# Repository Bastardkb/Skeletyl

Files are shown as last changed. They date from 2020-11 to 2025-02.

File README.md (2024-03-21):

# Skeletyl

Compact and silent Dactyl-like keyboard for ergo lovers.

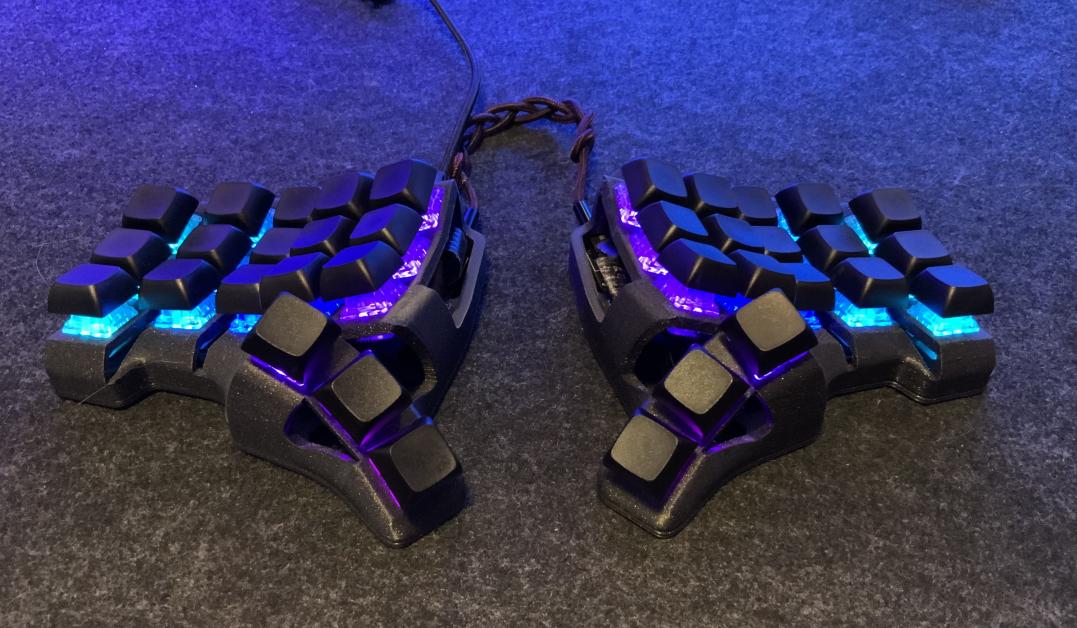
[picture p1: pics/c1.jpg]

*picture: trekdemow*

# Required components

## 3d prints

### Important note on V4/V3

The revision 4 of the skeletyl introduces drastic changes with the bottom plate. It reuses the positioning of the screws of the Charybdis Nano, so that the Organic tent can be re-used. It also uses new voronoi-style plates.

When choosing a model to print, be mindful of the version you choose. The files in the `V3` folder are **not** compatible with the V4 case and alien tents. Unless you want to use one of the `V3` mods, we recommend using the latest version `V4`.

### Print files and instructions

The STL files are included in this Github repository, in the `V4` folder.

Please find detailed instructions on how to print the case on the online instructions linked below.

| Description | File | Notes |
| --- | --- | --- |
| Right case | `V4/case_v4_vXY.stl` | XY version will vary |
| Left case | | Mirror the right case in your slicer |
| Right plate** | `V4/plates/plate_v4_vXY.stl` | XY version will vary |
| Left plate | | Mirror the right case in your slicer |
| Tent - right | [Charybdis nano tent](https://github.com/Bastardkb/Charybdis/tree/main/files/3x5%20nano/tent/alien) | Optional `Alien` tent, use the one from the Charybdis Nano* |
| Tent - left | | Mirror the right tent in your slicer* |

*If you are printing tents, there are multiple ones available for the Charybdis Nano, and only the `Alien` version is compatible with the Skeletyl V4. There are 30, 15 and 5 degrees versions available.

**There is also a DXF file included, if you want to laser-cut plates. See also the `magsafe` mod in the `mods` folder.

## Get a kit from BastardKB

You can get a full Kit, including case and all PCBs and electronics required on the shop:
https://bastardkb.com/

If you want to print the case yourself, you can also get just the electronics Kit.

## Electronic components

If you are sourcing the electronic components yourself, you can find a BOM in the [BOM](electronics_bom.md) file.

# Build guide

You can find detailed instruction on the online documentation linked below.

# Links

- Discord: https://bastardkb.com/discord
- Website: https://bastardkb.com/
- Docs: https://docs.bastardkb.com

# Forks

- [Reinforced, increased pinky stagger](https://github.com/dereknheiley/Skeleton-Dactyl-Mini)
- [Navtyl - with 5-way switch](https://github.com/Wimads/Navtyl)
- [skeletyl40 - 5x4 variant](https://github.com/bryankenote/skeletyl40)

# Mods
There are a variety of mods available in the `mods` folder, including a unibody case and chair mounts.

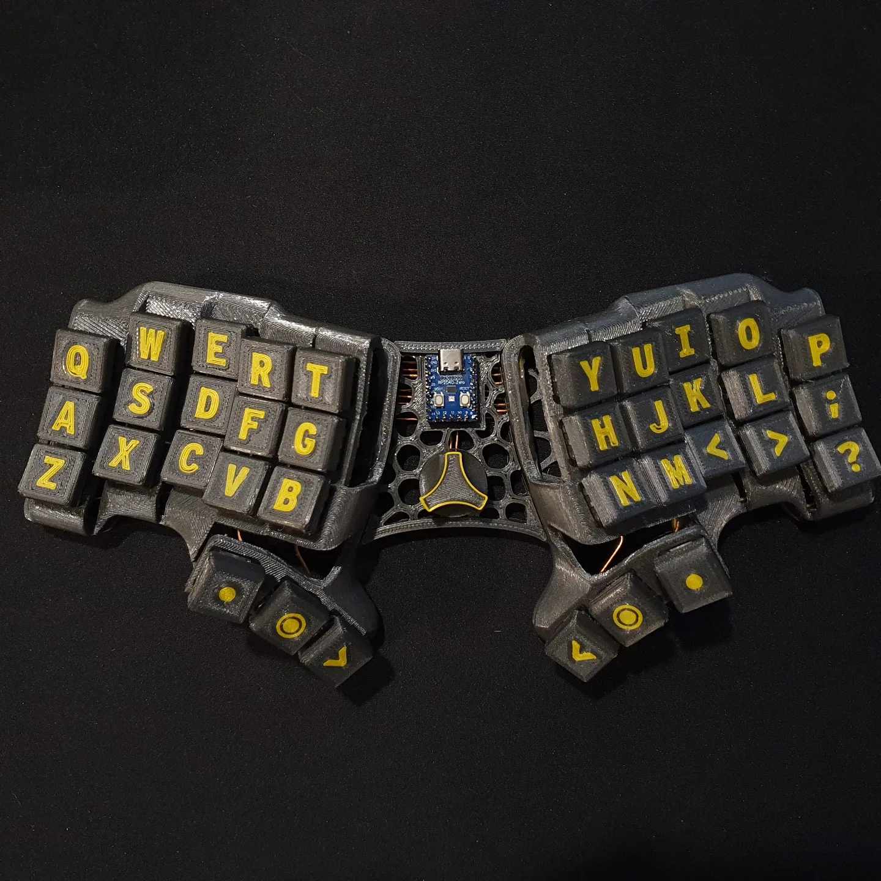
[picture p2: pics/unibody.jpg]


# License 

This work is licensed under a Creative Commons Attribution-NonCommercial-ShareAlike 4.0 International License.

# Versions

V1:

- original version

V2:

- smoother
- Compatible with amoebas and flexible pcbs
- more screws !

V3:

- better stronger screw inserts (added aliexpress link in readme)
- switch to adapter V1.4

V4

- change plate footprint to be compatible with the charybdis nano organic tent
- small visual improvements
- add version numbering on the case and plate

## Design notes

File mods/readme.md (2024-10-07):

# Table of contents

- [Table of contents](#table-of-contents)
- [Magsafe](#magsafe)
- [Unibody](#unibody)
- [Chair mount plate](#chair-mount-plate)
  - [V4 version plate](#v4-version-plate)
  - [V3 version plate](#v3-version-plate)
- [Pro micro mod](#pro-micro-mod)

# Magsafe

Is's possible to add tenting to your keyboard by using magsafe magnets and tripods.

The `magsafe` folder contains:
- STL files meant to be 3d printed and used with magnet stickers
- A DXF file meant to be laser cut

If you are ordering laser-cut plates, make sure to use a magnetic material such as steel.

# Unibody

*What if split keyboard, but not split?*

Files are in the `unibody` folder, including a holder for a RP2040 zero and a pro micro.j



# Chair mount plate  
## V4 version plate
Requires a 1/4-20 UNC heat insert. Standard 1/4 inch camera mount thread.
There is a version with bumpon stands so the keyboard can sit flat on a surface when not mounted.

## V3 version plate  
Alternate bottom plate for mounting to a chair or desk using standard camera mounting equipment. Fits 1/4 inch mounting bolt (1/4-20 UNC).  
  
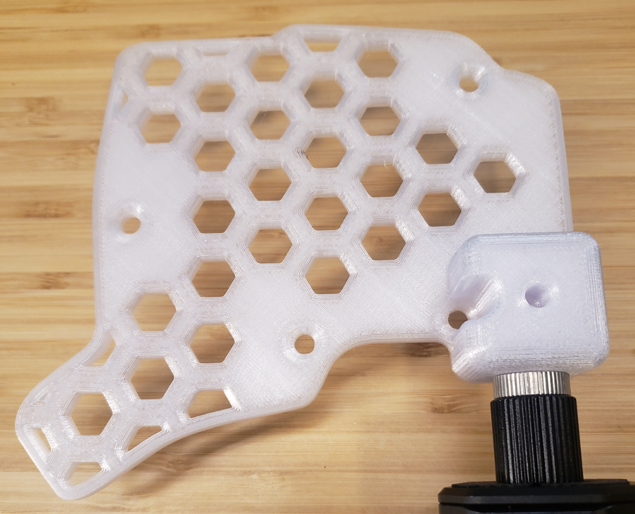
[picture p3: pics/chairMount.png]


# Pro micro mod

3d printable files to hold a pro micro in place of the splinktegrated PCB.

Files are in the `pro micro` folder.

# Tent plate

A solid tent made to house a battery. Connects to the standard plate at the bottom.

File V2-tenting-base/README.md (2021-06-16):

## Skeletyl Tenting base.

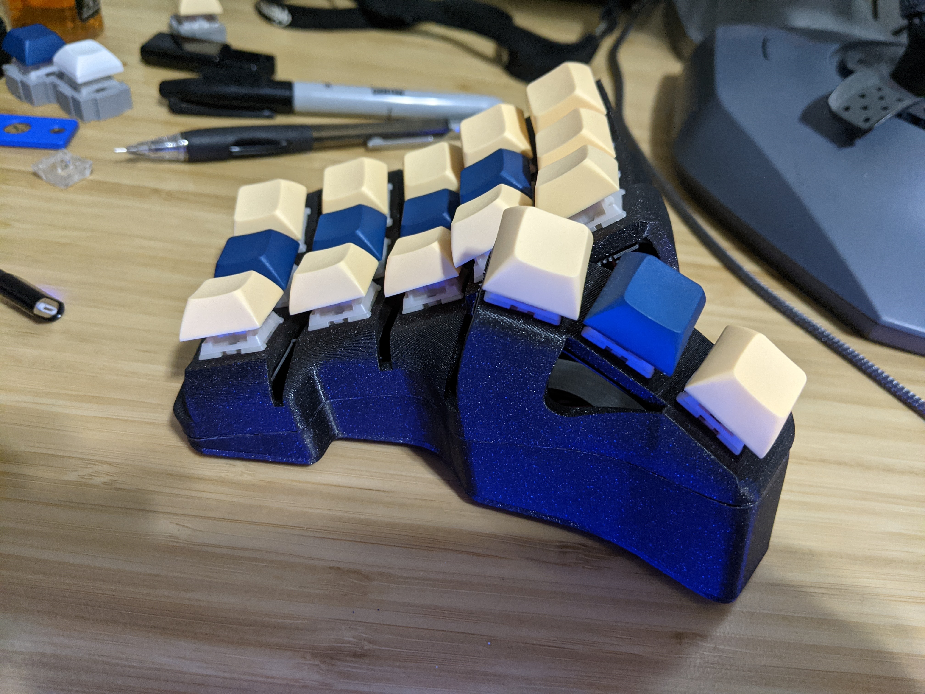
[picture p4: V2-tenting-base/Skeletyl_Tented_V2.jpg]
skeltyl tenting left side


This tenting base attaches to the bottom of the skeletyl and provides a 15 degree tenting angle and provides a new bottom plate to attach to the bottom of the tenting base.

STL files for the tenting base and the bottom plate are provided.  A prusa slicer project file is provided for the tenting base that contains the settings I used to successfully print the models.  A Fusion 360 file is provided so you can customize this as you see fit.  For example, the tenting is achieved with a construction plane cutting an extrusion and you can adjust this to achieve your desired tenting and tilting angles.

The tenting base has two holes in the back which are suitable for pushbuttons with M7threads / 7mm holes for reset and power switches.  Power?  Yes, this was designed bluetooth builds!  The bottom plate has a raised rectangular region and this is used to seat an 18650 battery holder.

### Assembly

Things you'll need to build it like me:

- The M4 machine screws that you have from the skeletyl hardware kit (or
  whatever screws go with the inserts you put into the skeletyl)
- Heat-set inserts M3 threads, 4mm thick, 5mm diameter.
- M3 machine screws
- Momentary switch (e.g. https://www.amazon.com/gp/product/B07BD2D96W )
- On/off switch (e.g.  https://www.amazon.com/gp/product/B07DWS195R )
- Battery holder (e.g.  https://www.amazon.com/gp/product/B0721Y3NDQ )
- 18650 battery.

The batteries are optional and only make sense if you are using a nice!nano controller and if that is the case you can of course use any battery that makes sense for you.
To assemble, install the M3 heat set inserts into the tenting base (not holes that are flat on both sides, *not* the countersunk holes).  Install the momentary and on/off swtiches.  Wire the momentary switch to RST and Ground on your microcontroller.  Wire the on/off swtich to your battery positive terminal and to the B+ connection on the nice!nano.  Connect your negative battery wire to the B- connection on the nice!nano.  Screw the tenting base to the skeletyl with the M4 machine screws, then screw the bottom plate to the tenting base with M3 machine screws.

### Flashing ZMK

If you are using a nice!nano, you'll need a ZMK shield for this keyboard.  See https://github.com/cwebster2/zmk-config for an example of a working setup for the skeletyl.

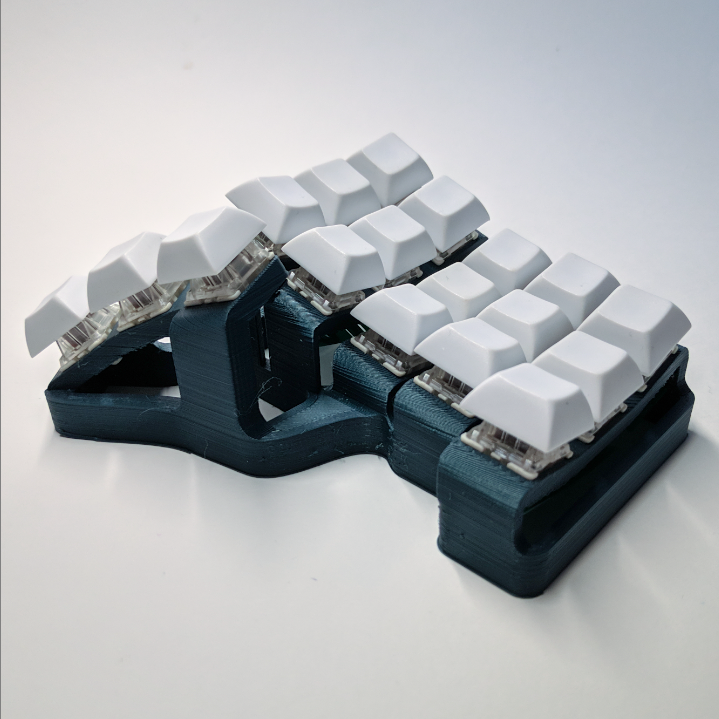
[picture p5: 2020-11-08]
pics/skel.png

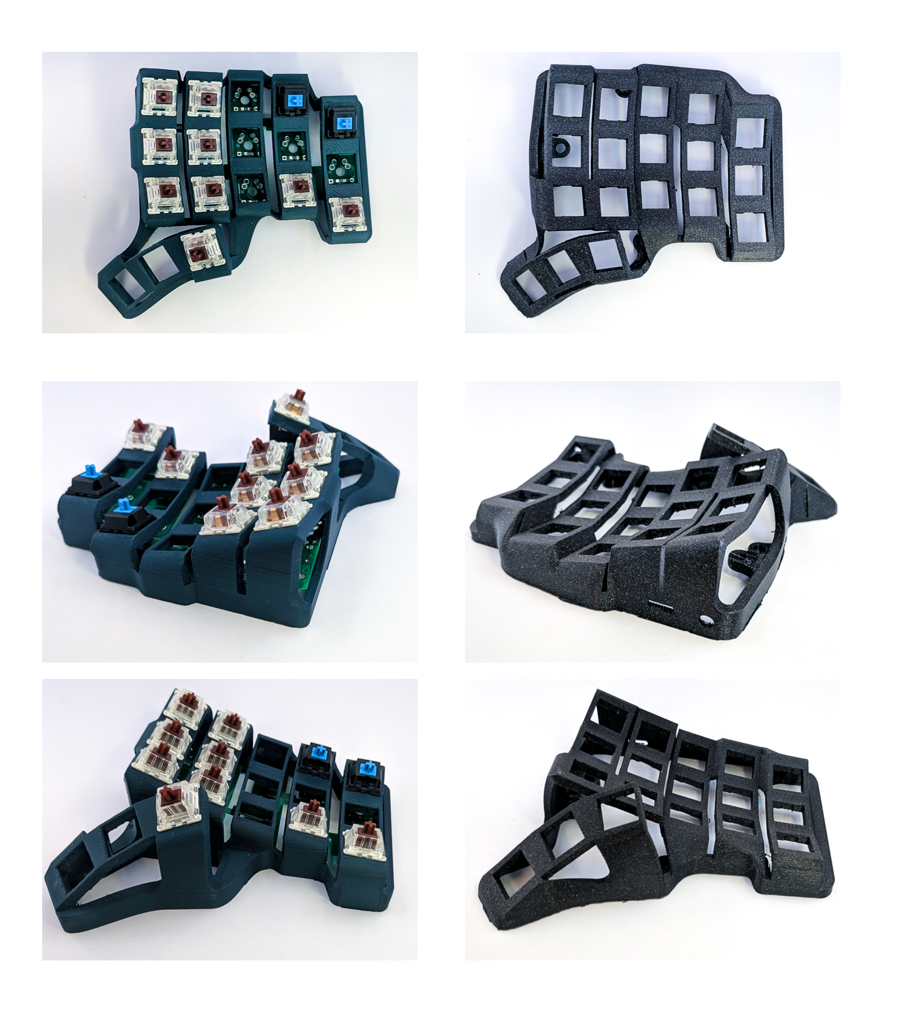
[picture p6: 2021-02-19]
pics/v1v2.jpg

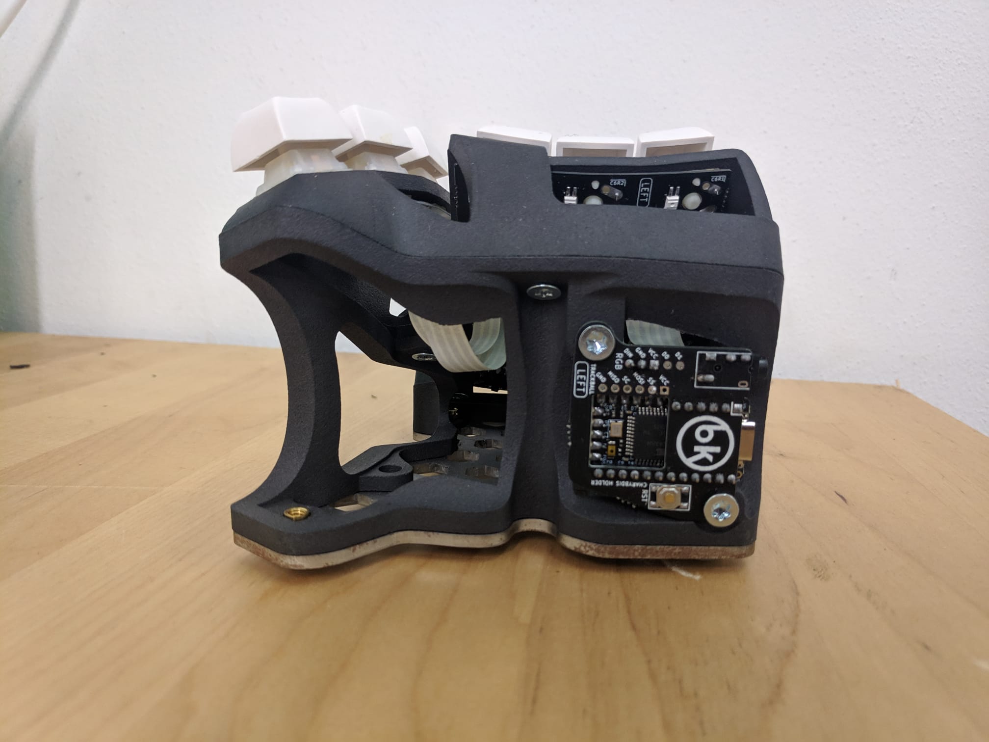
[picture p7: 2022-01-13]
pics/tent2.jpg

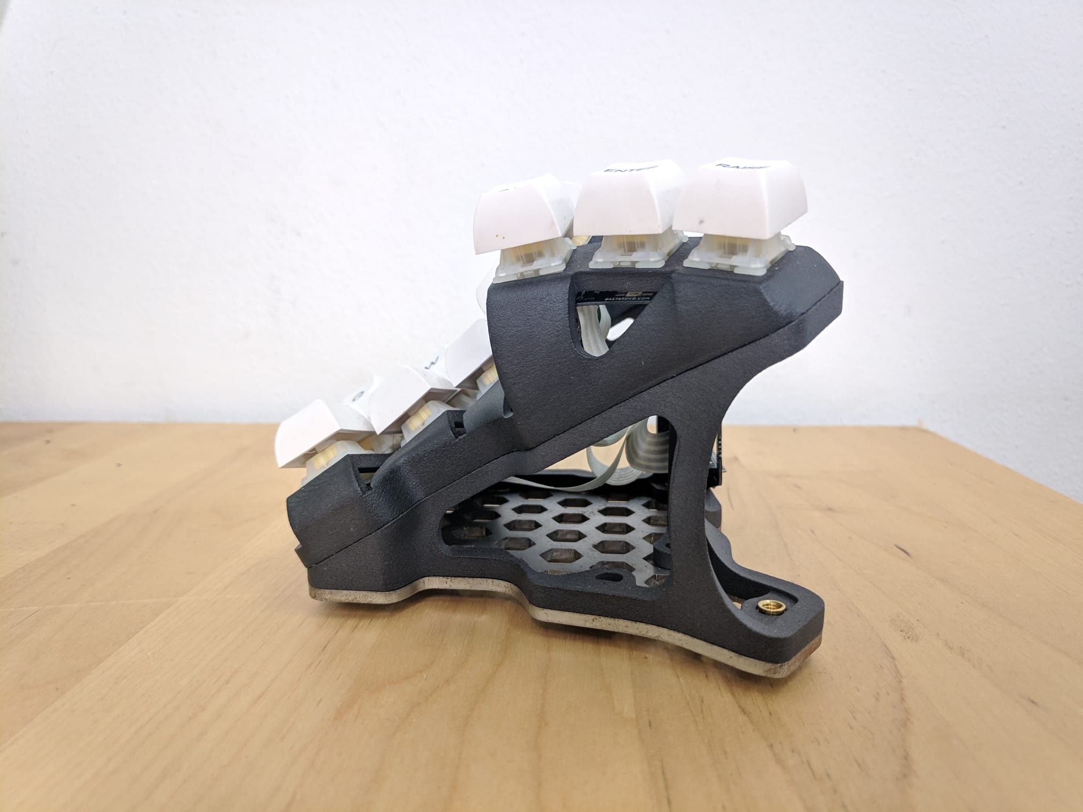
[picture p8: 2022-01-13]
pics/tent1.jpg

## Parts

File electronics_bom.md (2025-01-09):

Parts list:

| Part name | Amount | Link |
| --- | --- | --- |
| Flexible PCB for the plate | 2 | https://github.com/Bastardkb/Skeletyl-PCB-plate |
| Flexible PCB for the thumbs | 2 | https://github.com/Bastardkb/TBK-Mini-PCB-thumb-cluster |
| Splinktegrated | 2 | https://github.com/bastardkb/splinktegrated |
| SOD123 Diodes | 36 | |
| Ribbon cables Flexstrip | 34 | Farnell, Aliexpress |
| M4 8mm Torx Screw | 12 | Conrad |
| M4 screw insert, M4 X D6.0 X L5.0 | 12 | https://fr.aliexpress.com/item/4000232925592.html?spm=a2g0s.12269583.0.0.6aef4f282LZO4v |
| PJ320A audio jack | 2 | |
| Button, 4x4x1.5 | 2 | https://www.aliexpress.com/item/1005001304569553.html?spm=a2g0s.9042311.0.0.27424c4dDwgcp7 |

If you want RGB, you will also need:

| Part name | Amount | Format |
| --- | --- | --- |
| SK6812 Mini-E LEDs | 36 | |
| Capacitor, 1uF | 4 | 1206 |
| Resistor, 330Ohms | 4 | 1206 |
| Wires | | 28 AWG recommended, Black, Red, Color |
| Ribbon cables Flexstrip | 6 | |

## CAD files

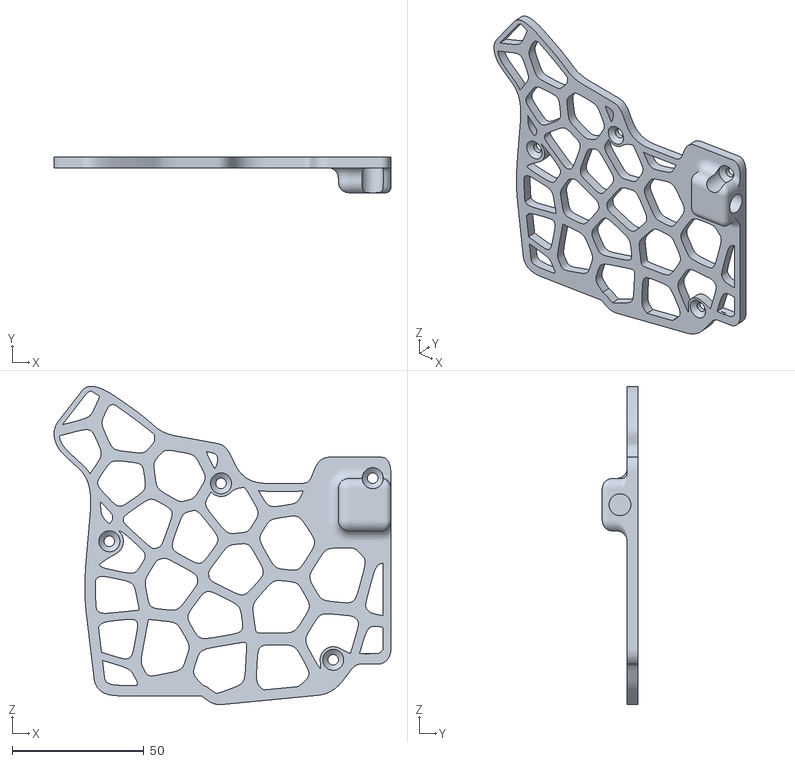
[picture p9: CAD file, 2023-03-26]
mods/chair mount/chair_mount_plate_side_v4_v9.stl
128.0 x 13.5 x 120.8

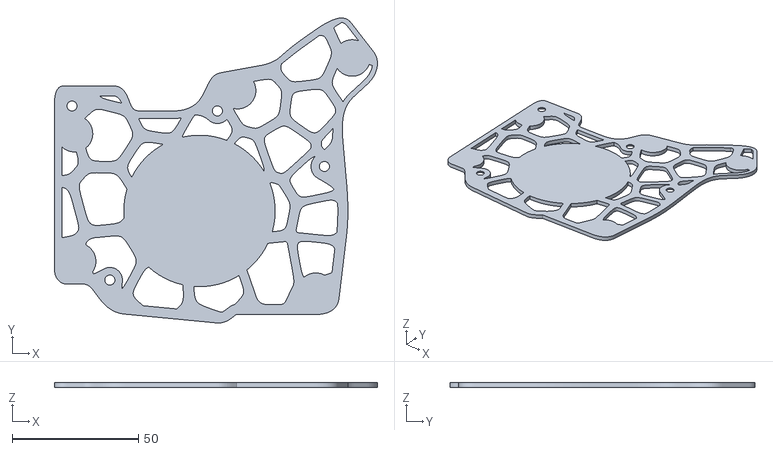
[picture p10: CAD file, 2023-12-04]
mods/magsafe/magsafe_3dp_v0_1.stl
128.0 x 120.8 x 2.00

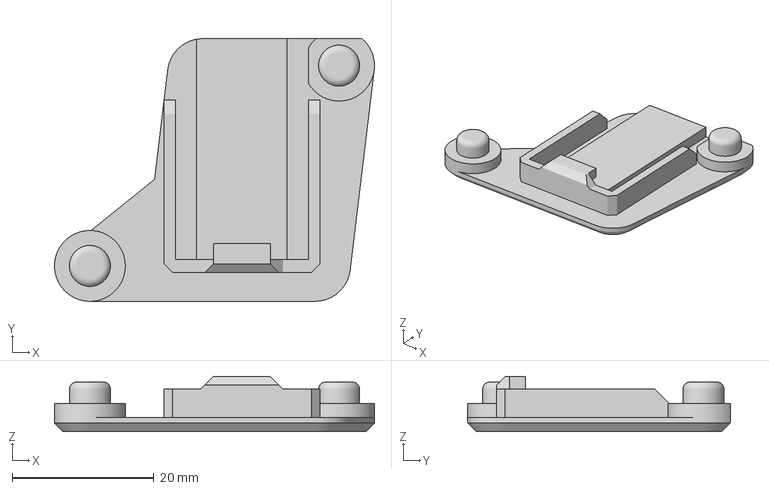
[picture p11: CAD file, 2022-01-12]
mods/pro micro mount plate/pro micro mount plate v2.3mf
45.2 x 37.1 x 7.80 mm

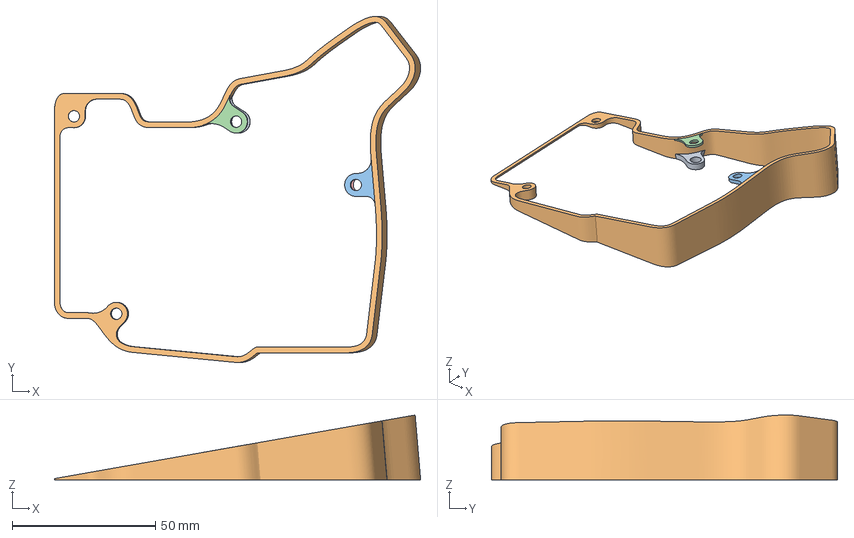
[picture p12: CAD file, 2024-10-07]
mods/tent_plate/tent_plate.3mf
128.0 x 120.9 x 22.7 mm

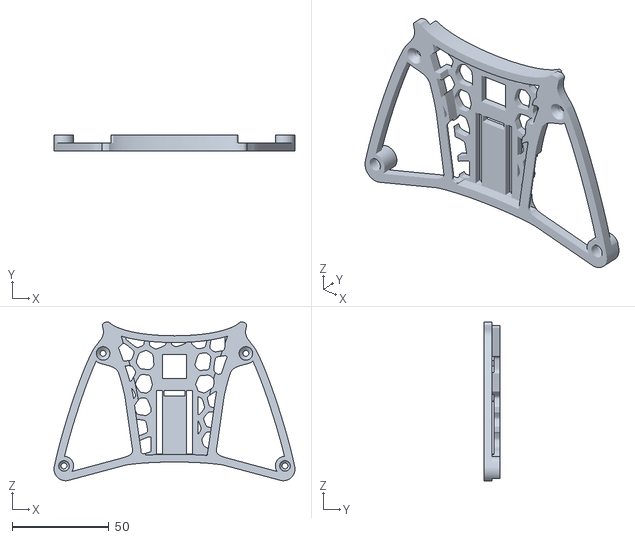
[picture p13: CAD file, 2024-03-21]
mods/unibody/Promicro/promicro.stl
124.4 x 8.00 x 81.8

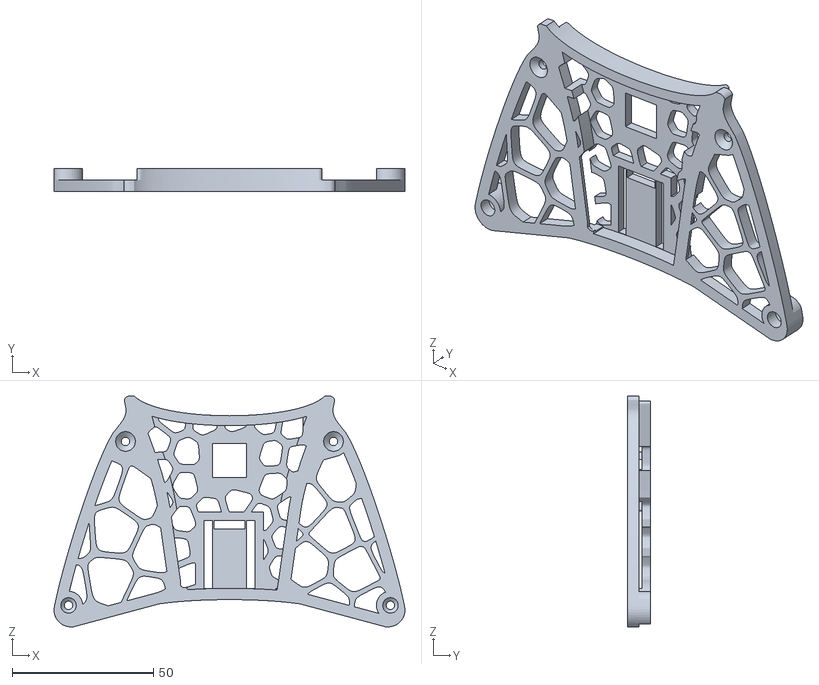
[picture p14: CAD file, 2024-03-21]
mods/unibody/RP2040 zero/rp2040 voronoi.stl
124.4 x 8.00 x 81.8

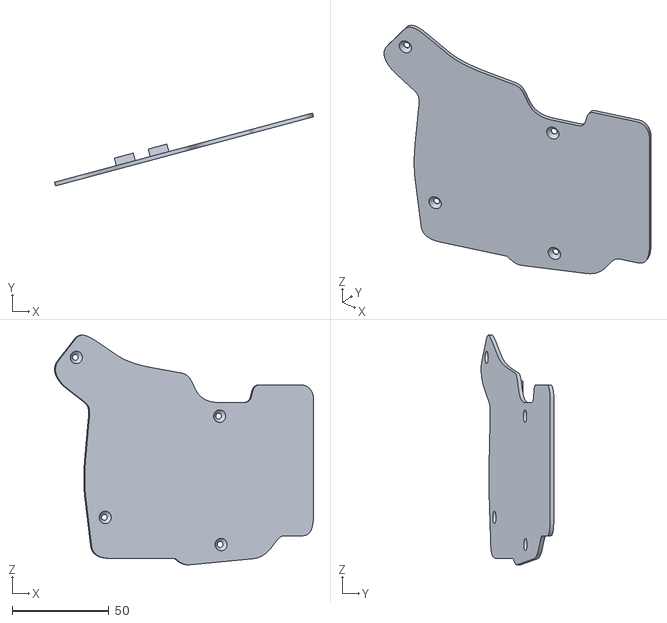
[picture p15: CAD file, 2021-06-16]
V2-tenting-base/Skeletyl_Tented_v2 v19_BottomPlate.stl
134.0 x 37.7 x 118.8

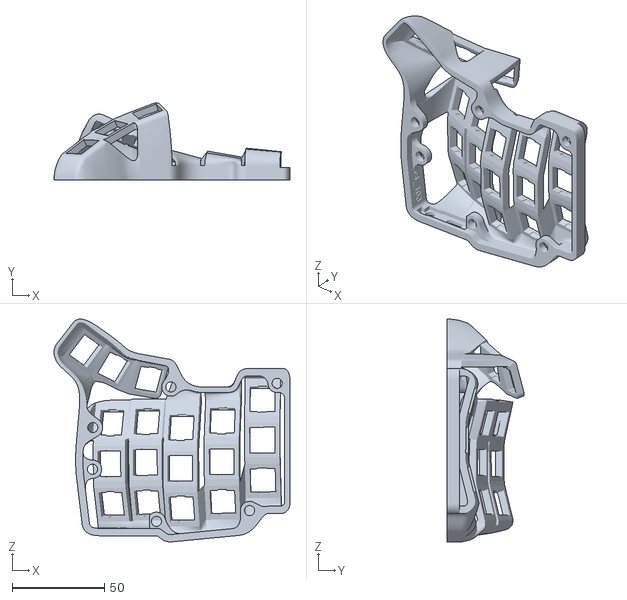
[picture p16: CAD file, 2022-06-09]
V4/case_v4_103.stl
128.0 x 42.0 x 120.9

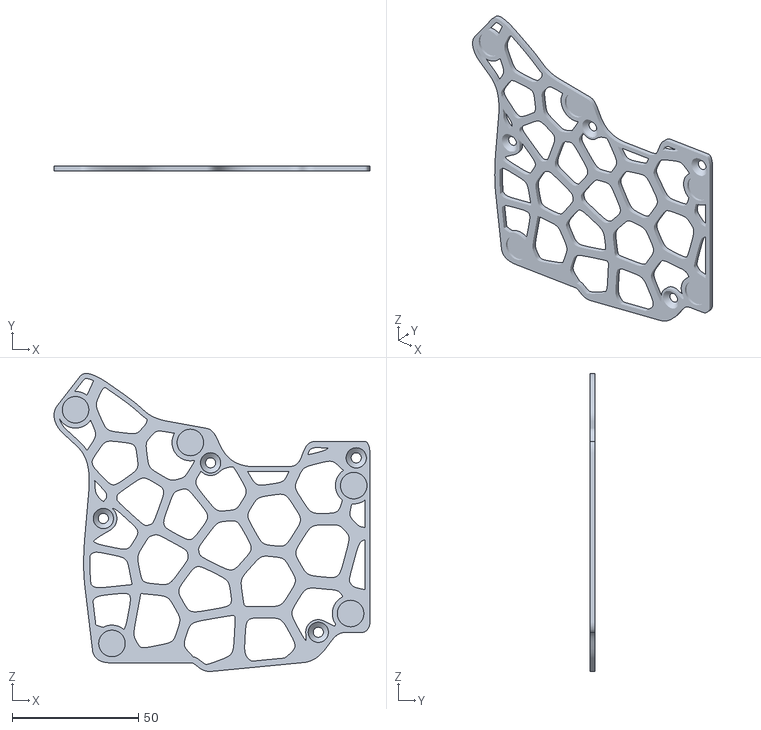
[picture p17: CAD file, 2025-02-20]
V4/plates/plate_flush_v2_3.stl
125.0 x 2.00 x 117.9

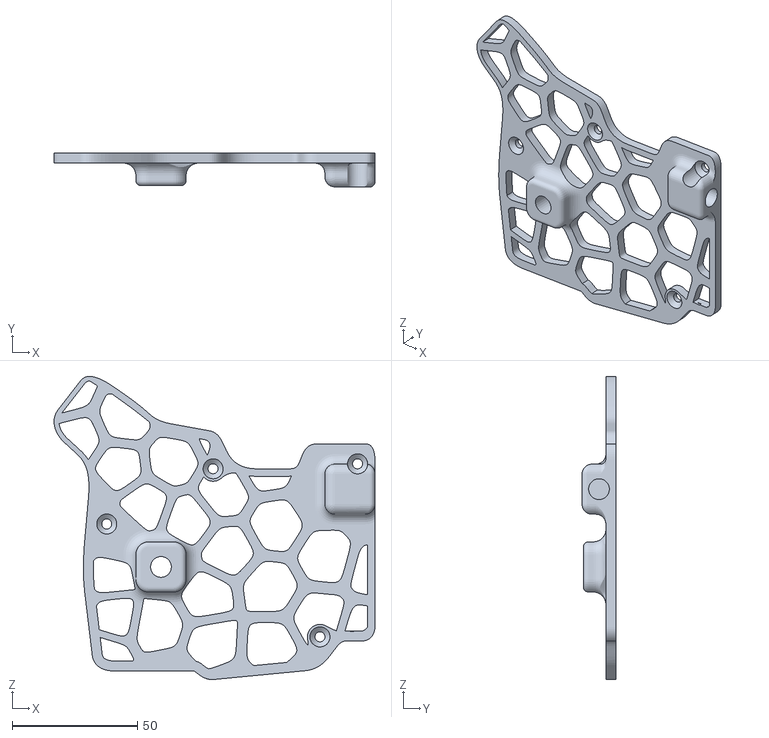
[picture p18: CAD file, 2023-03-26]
mods/chair mount/chair_mount_plate_side_bottom_v4_v9.stl
128.0 x 13.5 x 120.8

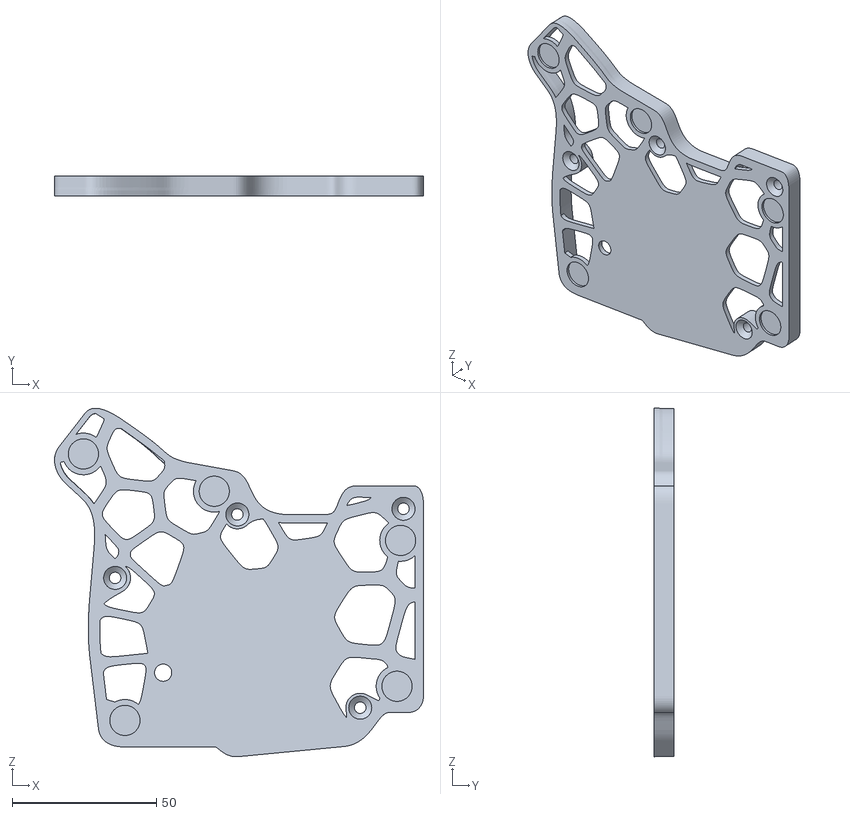
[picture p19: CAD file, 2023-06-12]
mods/magsafe/Skeletyl_v4 v105-plate-patched-spacer.stl
128.0 x 7.00 x 120.9

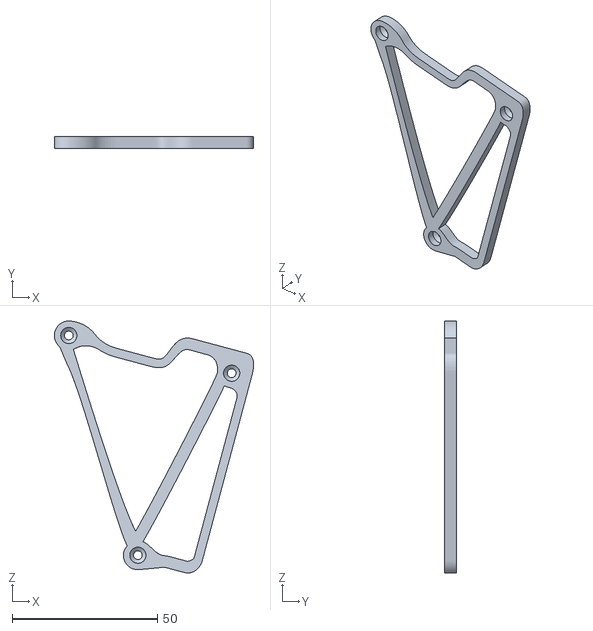
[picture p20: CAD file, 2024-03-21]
mods/unibody/Promicro/promicro side.stl
68.7 x 4.00 x 86.9

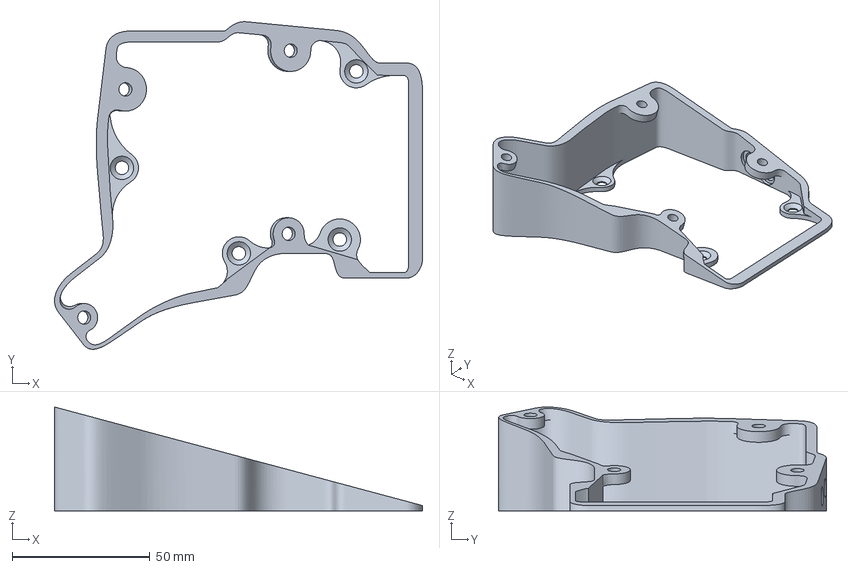
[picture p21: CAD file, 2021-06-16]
V2-tenting-base/Skeletyl_Tented_v2 v21_TentingLayer.3mf
133.5 x 118.8 x 37.7 mm

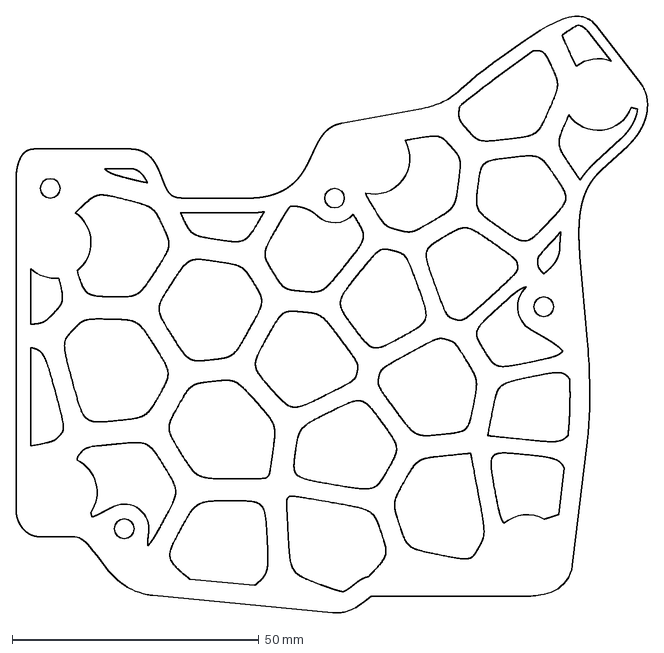
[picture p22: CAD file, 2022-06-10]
V4/plates/plate_v4_v103.dxf
128.0 x 120.9 mm

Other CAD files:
V4/case_v4_v99.step
mods/magsafe/Skeletyl_v4 v105-plate-patched.stl
mods/unibody/Promicro/promicro voronoi side.stl
V1/case_v9.step
V1/case_v9.stl
V1/plate_v9.step
V1/plate_v9.stl
V2-tenting-base/Skeletyl_Tented_v2 v21_TentingLayer.stl
V2-tenting-base/Skeletyl_Tented_v2 v22.f3d
V2/Skeletyl_v2_v7.step
V2/case_v2_v7.stl
V2/plate_v2_v5.stl
V2/tent30deg_v7.stl
V3/Skeletyl_v3 v7.step
V3/blackpill/case_blackpill_v1.stl
V3/case_v3_v12.stl
V3/plate_metal_cutting.dxf
V3/plate_v3_v5.stl
V3/tent/tent30deg_bottomplate_v38.stl
V3/tent/tent30deg_v10.stl
V3/tent/tent30deg_withbottomplate_v10.stl
V4/plates/plate_v4_103.stl
archive/V1/case_v9.step
archive/V1/case_v9.stl
archive/V1/plate_v9.step
archive/V1/plate_v9.stl
archive/V2-tenting-base/Skeletyl_Tented_v2 v21_TentingLayer.stl
archive/V2-tenting-base/Skeletyl_Tented_v2 v22.f3d
archive/V2/Skeletyl_v2_v7.step
archive/V2/case_v2_v7.stl
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

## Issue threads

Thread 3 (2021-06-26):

Compatibility with a regular pro micro

toniz4, 2021-06-26:
In the parts list it says that a elite c is needed to build this keyboard, but a regular arduino pro micro would work? Without any modifications or light modifications? If any modification is needed, how one would make those modifications?

Thanks.

bstiq, 2021-06-27:
Hello,

Thank you for getting in touch !
The case model is indeed made for elite-Cs - the hole in the case is he
size of USB-C.
I reckon a pro micro should work though !

Regards,

*Quentin LEBASTARD*

Le sam. 26 juin 2021 à 05:48, Cássio Ávila ***@***.***> a
écrit :

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

toniz4, 2021-06-27:
How one would go about remodeling the hole to fit exactly a regular pro mico? Sorry I know nothing about 3D modeling.

bstiq, 2021-07-02:
Hey sorry didn't see your reply.
If you don't know anything about fusion modeling, it's going to be difficult.

I've seen a few people using a pro micro with hotglue, so it should be no problem !

Regards,

Closed 2021-07-12.

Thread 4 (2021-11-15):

Question on mounting the Elite-C using the 3D-printed shield adapter

cyanindya, 2021-11-15:
Hello, first, thank you for designing this awesome keyboard! I'm about to start building it and decided to go for handwired approach since it is difficult to get flexible PCB here, and while I mostly get the gist of the building process so far, there is something that still lost to me. Specifically, regarding use of printable shield adapter from Geoff, since I am still unfamiliar with 3D printing in general.

This may seem mundane, but with the 3D-printed adapter, how am I supposed to mount the Elite-C to it? In the Dometyl repository, it is stated that I can solder around or glue the components to it, but I am still a bit lost about the exact process. Say that if I am to use solder to "lock" the Elite-C to the adapter, since it is 3D-printed, will it be possible for the process to accidentally melt the adapter and mess up both the printed adapter and the Elite-C? Or if the glue approach is better, what kind of glue that is safe to use, and at which spots should they be applied to?

With the use of the adapter PCB, I understand perfectly well the process (i.e. the soldering), but it is difficult to find local PCB manufacturer in my place that can print using 1mm PCB, hence why I'm considering to go for the printable shield adapter instead.

Thank you!

geoffder, 2021-11-16:
Hey there, I hope that these [pictures of a recent build of mine](https://github.com/geoffder/dometyl-keyboard/tree/main/things/boards/niztyl) can be of some help. When I said "solder around" I was suggesting that you might use headers, then solder on to the other side, or plug connectors on to the pins. What I found worked for me was soldering on some select headers, and using those to line up the MCU for hot gluing over the holes. Then I just soldered into the pinholes on the side facing out.

Now that there are those build images (which didn't exist when I first added those notes, it may be time to revise it and add a link.

cyanindya, 2021-11-16:
It's clear enough so far, thank you - it makes sense now! May I ask what specific glue that you used, or similar ones those should be safe?

geoffder, 2021-11-16:
I just used the glue that came with [this gun](https://www.amazon.ca/Chanseon-Industrial-Adjustable-Temperature-Nozzles/dp/B08PPC5VTR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). I'm sure most hot glue sticks will be safe / strong enough for this use case though.

cyanindya, 2021-11-16:
That should be clear enough - thank you! Then I'll close the inquiry for now.

Closed 2021-11-16.

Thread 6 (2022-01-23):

Blackpill Build details

camrbuss, 2022-01-23:
What is the difference between the blackpill case and the normal case?

Will an adapter board be created for the blackpill?

What are the suggested print settings for the organic tent? Does it require support material?

Love this keyboard! Thanks for open-sourcing all the hard work of your designs.

bstiq, 2022-01-24:
Hello,

The blackpill case is made to work with the blackpill shield available here:
https://github.com/Bastardkb/adapter-blackpill/
It's a work in progress though - we confirmed hardware and firmware work for the Charybdis Nano, but we're still working on adding features (look at the issues of the repo if you want a better idea).

For the organic tents you should add supports everywhere (not only on the bed).

Thank you for the kind words ! I'm glad you like the keyboard.
On a sidenote, I just ordered the flexible PCBs with per-key RGB for the skeletyl, if you want to order those as well :)

Regards,

Closed 2022-01-24.

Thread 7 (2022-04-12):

Possibility of adding case variant for hotswappable mcu

karrui, 2022-04-12:
Thanks for open sourcing the case! As the mcu hotswap spacers are slightly taller than their non hotswap variant, the USB-C cutouts do not line up correctly when used with a hotswapped mcu.

Is it possible to request for a case variant with repositioned USB-C cutout to fit a hotswapped mcu?

karrui, 2022-04-12:
> I recommend using either millmax sockets,

I'm using the hotswap sockets from [kriscables](https://kriscables.com/product/mill-max-low-profile-sockets/), which are slightly higher than the default spacer height. Are there shorter sockets I am not aware of? :(

Ah, neglected to also mention that I am already using the rev2 shield PCB! Is there an image of how to the hotswapping of ribbon cables are done?

I am not familiar with editing the step file at all, but am willing to try if a step file is provided! :)

bstiq, 2022-04-14:
Hey,
I don't think the peelaway should work.
I recommend using the millmax on the matrix headers.
That way I have multiple shields each with a different MCU, and I just have to disconnect the cables when I want to switch.

Maybe this picture makes it clearer?
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

Regards,

karrui, 2022-04-15:
Ah, you solder the mcu and allow the breakout pcb to be hotswapped instead. I was planning to make the entire mcu hotswappable ala https://docs.splitkb.com/hc/en-us/articles/360011263059-How-do-I-socket-a-microcontroller-

However, at this point I'm about to just socket the mcu directly instead of going through all that trouble, haha!

bstiq, 2022-04-17:
Hello,

This is correct.
Since it seems you are going ahead with the build I am closing this issue, have fun !

Regards,

karrui, 2022-04-17:
Oops, I should have closed it myself.

For others who stumble onto this issue in the future, millmax 315 sockets are the exact height as the default header pins that come with nice!nano and works perfectly. millmax 310 sockets (the higher profile variant) will not work.

PS: millmax 315/310 sockets work perfectly to also hotswap the ribbon cable.

Closed 2022-04-17.

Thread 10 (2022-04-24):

Question: Why not combine the main PCB with the Thumbs PCB?

mr-september, 2022-04-24:
Is there any negative effects from doing so? It seems a lot cheaper to order PCBs this way, since the main PCB has a very big unused area in the bottom right corner, so replacing that with the Thumbs PCB will only add ~7.7 mm to the combined outer dimension.

bstiq, 2022-04-24:
Hey,

Here's a couple reasons:

- the charybdis keyboard uses the same plate, but a different thumb cluster
- it increases the total size of the pcb, so more expensive
- it makes it 2 designs in the pcb instead of just 1 - most manufacturers will charge more  because of this
- it ties together the 2 pcbs - updating one also means updating the other. Sometimes only the plate needs an update, sometimes I want to prototype on the thumb cluster, so it's nice to have them decoupled

Closed 2022-04-24.

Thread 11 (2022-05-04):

V4

bstiq, 2022-05-04:
In progress.

Improvements:

- same screw and thumb cluster placement as charybdis nano, to be able to reuse the tent
- replacement of the thumb keys so that the cluster fits better
- thumb cluster a bit higher and closer, like on the cnano
- make jack hole larger like on cnano

bstiq, 2022-05-04:
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
round these corners

bstiq, 2022-05-06:
Moved this to PR.

Closed 2022-05-06.

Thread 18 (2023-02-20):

OLED Display Support

dhruvinsh, 2023-02-20:
Hi,
Thank you for your great work, and thank you keeping it opensource and providing regular updates.

Are you in the future (or currely by the user) possible to add 0.91 OLED display (128x32)?

If you are planning that is great or not then I need some advice. If you had to put where would you plan to do it? I am thinking of the gap on the both side of keyboard but angle differently so that it is easy to view.

bstiq, 2023-02-21:
Hey,

I'm not planning to add OLEDs to my 3d keyboards.
The shield PCB used in them does have a header for I2C, with optional pull-up resistors. So you could connect your oled to that, probably using cables to extend it.

As for where to position them on the keyboard exactly - I'm not sure. You could design eg. an addon that screws into the plate and holds the oled.
Another option is to use the organic tents that have holes for screw inserts on the side, to connect that addon. I explored a similar concept when designing the trackpad holder here: https://github.com/Bastardkb/Charybdis/tree/main/files/mods/trackpad

Feel free to update us if you end up doing some design, here or on discord, and PR it !

dhruvinsh, 2023-03-07:
Thanks for your answer. I would like to keep this ticket open for now and I am definately plan to work on it to accomodate the OLED. I am just waiting to arrive them and I will give it a go for design.

haShinui, 2023-11-30:
Any update on the OLED configuration?

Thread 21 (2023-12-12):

Heat set insert clarification

matthews-jca, 2023-12-12:
Build list mentions "M4 screw insert, M4 X D6.0 X L5.0" but the link supplied shows 4mm length. Also measuring the supports in the printed case show them to be 4mm length as well. Should these be 4mm or 5mm long?

bstiq, 2023-12-13:
Hello,

The page automatically selects the L4, there is no way to add a link that selects the required L5.
For the builds, we use and recommend L5, though L4 might work

Closed 2023-12-13.

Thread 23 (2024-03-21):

Spatial dimensions?

ferrosa, 2024-03-21:
Could you please provide the spatial dimensions of the finished build (keycaps on)?

Reason: I have a below-table keyboard slot of 11cm height, which is perfect for my conventional keyboard (Cherry peaking at ~4.5cm), but might be tight with a Skeletyl (+ fingers). It's arguably simpler for you to measure it than for me to test print a mockup just for height fitting. Also, I'm not holding out any hope for tenting.

bstiq, 2024-03-21:
Hey,

I measure around 5.5cm with DES keycaps and no tents.
With hands, it seems to fit under 10cm.

ferrosa, 2024-03-21:
Thanks for the info! Looking good, will order a kit from your website soon.
Also impressive response time.

Closed 2024-03-21.

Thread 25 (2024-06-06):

[QUESTION] There is any variant with hotswap support? (handwiring)

IronArthur, 2024-06-06:
I'm searching for any variant but i can't find any info. I wanted to try to print an skeletyl with kailh hotswap connectors to try different switches.

bstiq, 2024-06-06:
Hey,

Hotswap is not officially supported, you can read more here:
http://docs.bastardkb.com/faq.html#hotswap

Closed 2024-06-06.

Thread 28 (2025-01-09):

TRRS Jack Clarification

rorychatterton, 2025-01-09:
Can you please clarify which TRRS socket you are using? I am struggling to find the part with the same pin out as shown in the pictures.

bstiq, 2025-01-09:
Good feedback, done now!

rorychatterton, 2025-01-09:
Thanks!

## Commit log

2020-11-08 add step files
    [case_v9.step, plate_v9.step]
2021-02-12 move to V1
    [case_v9.step, case_v9.stl, plate_v9.step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]
2021-02-13 add v2
    [case_v2_v5.stl]
2021-02-13 add plate
    [plate_v2_v5.stl]
2021-02-13 Create Skeletyl_v2 v6.step
    [Skeletyl_v2 v6.step]
2021-02-20 move screw holders to accomodate new mcu holder pcb
    [case_v2_v5.stl, case_v2_v7.stl]
2021-02-20 Create Skeletyl_v2 v7.step
    [Skeletyl_v2 v7.step]
2021-02-20 file names
    [Skeletyl_v2 v6.step, Skeletyl_v2_v7.step]
2021-04-05 Add my tenting base for the skeletyl V2 (#2)
    * Add fusion project and stls
    * Add revisions
    * Increase hole diameter for momentary switch
    * Add it all for now
    * Cleanup
    * Add readme and picture
    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
    [Skeletyl_Tented_v2 v19_BottomPlate.stl, Skeletyl_Tented_v2 v21_TentingLayer.3mf, Skeletyl_Tented_v2 v21_TentingLayer.stl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]
2021-04-09 switch to adapter 1.4
    [case_v3_v5.stl]
2021-04-09 add screw insert link
2021-04-09 add fusion file
    [case_v3_v5.stl]
2021-04-25 add plate with anti slip pads
    [plate_v3_v5.stl]
2021-04-28 more space for shield pcb
    [case_v3_v5.stl, case_v3_v6.stl]
2021-05-09 add tent and fusion file
    [tent_30deg.stl]
2021-07-15 add anti slip pad
    [tent30deg_v9.stl, tent_30deg.stl]
2021-08-05 fix screw hole orientation
    [tent30deg_v10.stl, tent30deg_v9.stl]
2021-08-17 Create Skeletyl_v3 v7.step
    [Skeletyl_v3 v7.step]
2021-09-06 better fitting for shield and ports
    [case_v3_v12.stl, case_v3_v6.stl]
2021-12-17 add chamfers
    [tent30deg_bottomplate_v10.stl, tent30deg_bottomplate_v35.stl]
2022-01-12 added Pro Micro mount plate (#5)
    [pro micro mount plate v2.3mf, pro micro mount plate v2.f3d, pro micro mount plate v2.stl]
2022-01-12 blackpill stuff
    [case_blackpill_v1.stl, tent30deg_bottomplate_v35.stl, tent30deg_bottomplate_v38.stl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]
2022-01-12 move stuff
    [Skeletyl_Tented_v2 v19_BottomPlate.stl, Skeletyl_Tented_v2 v21_TentingLayer.3mf, Skeletyl_Tented_v2 v21_TentingLayer.stl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]
2022-01-22 stronger screw insert holes for nylon
    [tent30deg_organic_plate_attachment_v38.stl, tent30deg_organic_plate_attachment_v39.stl]
2022-02-11 switch to only one organic tent
    [tent30deg_bottomplate_v35.stl, tent30deg_bottomplate_v38.stl, tent30deg_organic_plate_attachment_v35.stl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]
2022-04-14 Update screw direction and add chamfers (#8)
    Thanks !
    [tent30deg_organic_plate_attachment_v39.stl, tent30deg_organic_plate_attachment_v42.stl]
2022-05-06 Add chair mount plates (#9)
    * added chair mount plates
    * Added mod section to readme with picture
    [ChairMountplate_v3_v8.step, ChairMountplate_v3_v8.stl]
2022-06-08 Rev 4 (#12)
    * new case and voronoi plate
    * move to archive
    * pull changes from main into rev4 (#13)
    * Update screw direction and add chamfers (#8)
    * Add chair mount plates (#9)
    * move mod files
    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
    [ChairMountplate_v3_v8.step, ChairMountplate_v3_v8.stl, Skeletyl_v3 v7.step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]
2022-06-08 update dxf
    [plate_v4_v103.dxf, plate_v4_v98.dxf]
2022-06-08 remove old V3 stuff
    [ChairMountplate_v3_v8.step, ChairMountplate_v3_v8.stl, tent30deg_organic_plate_attachment_v42.stl]
2022-06-09 bigger screw inserts for nylon
    [case_v4_103.stl, case_v4_v99.stl]
2022-09-26 Added v4 chair mount plate (#14)
    * Added new chair mount for v4
    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
    [ChairMountplate_v3_v8.step, ChairMountplate_v3_v8.stl, chairMountBumpons_v4 v2.stl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]
2022-10-17 Added bottom and side mount plate (#16)
    * added side bottom mount option
    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
    [chairMountBumpons_v4 v2.stl, chairMount_v4 v6.stl, chair_mount_plate_side_bottom_v4_v9.stl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]
2022-12-15 move chair mount files
    [ChairMountplate_v3_v8.step, ChairMountplate_v3_v8.stl]
2023-03-13 add magnet plate
    [plate_magnet_v1.dxf]
2023-06-12 feat: adding patched plates for use with magsafe stickers (#19)
    * feat: adding patched plates for use with magsafe stickers
    * move files around
    ---------
    [Skeletyl_v4 v105-plate-patched-spacer.stl, Skeletyl_v4 v105-plate-patched.stl, plate_v3_v5-patched-spacer.stl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]
2023-12-04 Add skeletyl 3dp magsafe plate (#20)
    [magsafe_3dp_v0_1.stl]
2024-03-21 Mods and BOM cleanup (#24)
    * mods organize
    * BOM
    * Update README.md
    * Update README.md
    * Update README.md
    * Update electronics_bom.md
    [Skeletyl_v4 v105-plate-patched-spacer.stl, Skeletyl_v4 v105-plate-patched.stl, chair_mount_plate_side_bottom_v4_v9.stl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]
2024-10-07 MOD: add tent plate to mods folder (#26)
    * add tent plate
    * rename folder, add readme description
    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
    [tent_plate.3mf, tent_plate.f3d, tent_plate.stl]
2025-02-20 add flush plate
    [plate_flush_v2_3.stl]
